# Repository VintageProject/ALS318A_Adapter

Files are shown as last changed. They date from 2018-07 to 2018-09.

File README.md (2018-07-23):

# ALS318A_Adapter
ALS318A to 2x 2364AS adapter for KIM Uno

This board allows to use a Russian ALS318A display to be used with the KIM Uno. It connects the 17-pin connector to a dual 2364AS footprint matching the KIM Uno board.
As the ALS318A is a common cathode type display, the KIM Uno software needs to be adjusted for use with CC displays, too.

Footprint position has been checked against the original KIM Uno board. 
Take care of pin clearances. Solder pins flush to board and use insulating layers if necessary.

Revision 00: Board outline matched to top of KIM Uno board. Might be bulky and interfere with power switch and other connectors.

Revision 01: Short board to match the size of the ALS318A board. Shouldn't interfere with other connectors.

Disclaimer: This is an untested training design. I won't be liable for any damage to your computer and/or electronics if you decide to use it. Use at your own risk.

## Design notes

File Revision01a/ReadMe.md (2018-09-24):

ALS318A to 2x 2364AS adapter for KIM Uno

This board allows to use a Russian ALS318A display to be used with the KIM Uno. It connects the 17-pin connector to a dual 2364AS footprint matching the KIM Uno board. As the ALS318A is a common cathode type display, the KIM Uno software needs to be adjusted for use with CC displays, too.

Footprint position has been checked against the original KIM Uno board. Board outline has been changed so that the adapter board has roughly the size of the ALS318A module. When soldering take care to leave enough room between the header pins and the Arduino pins.
Pin spacing has been changed to 2.5 mm for the ALS318A, and position was adjusted to centred.

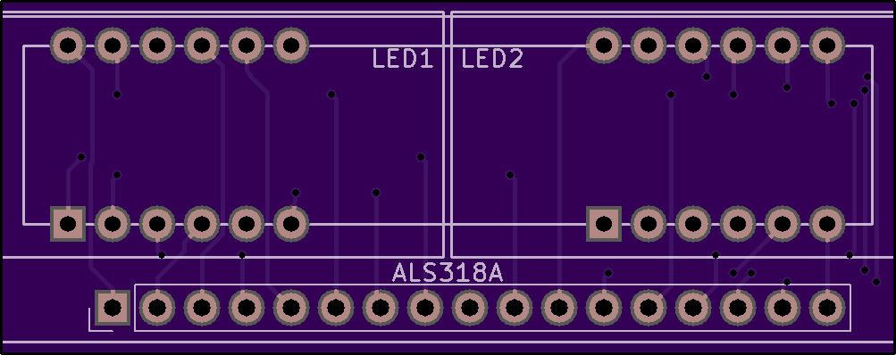
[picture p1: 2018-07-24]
Revision 01/KIMUno ALS318A Display Adapter Rev 01 Gerber Top Render.png

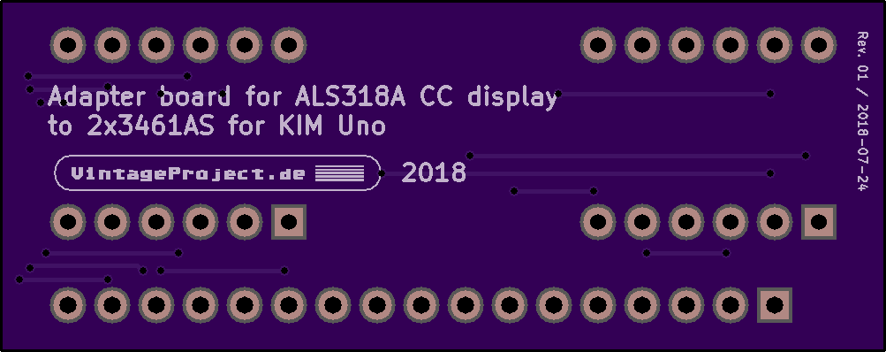
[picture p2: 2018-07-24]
Revision 01/KIMUno ALS318A Display Adapter Rev 01 Gerber Bottom Render.png

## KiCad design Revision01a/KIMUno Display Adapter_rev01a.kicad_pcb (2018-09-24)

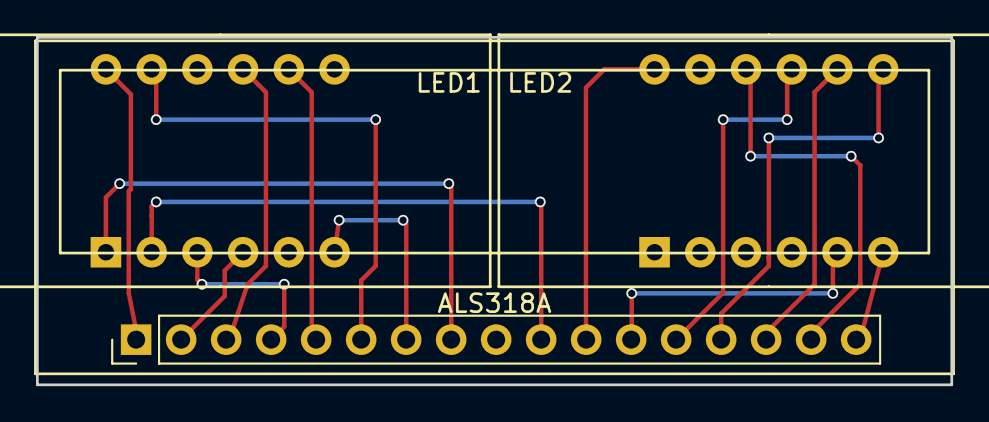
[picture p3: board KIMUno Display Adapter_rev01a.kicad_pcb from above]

Board: 2 copper layers, 50.8 x 19.3 mm, 4 parts (0 on the bottom side), 16 nets.

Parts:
 : LOGO_VintageProject_B.SilkS
J1: ALS318A; ALS318A_BubbleLED_2.5mm
LED1, LED2: CC56-12; 3461AS-BS_4x7SEG-DIGIT_9mm

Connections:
/CC1: J1.1, LED1.12
/CC2: J1.3, LED1.9
/CC3: J1.5, LED1.8
/CC4: J1.7, LED1.6
/CC6: J1.11, LED2.12
/CC7: J1.13, LED2.9
/CC8: J1.15, LED2.8
/CC9: J1.17, LED2.6
/Seg_1a: J1.6, LED1.11
/Seg_1c: J1.2, LED1.4
/Seg_1d: J1.10, LED1.2
/Seg_1e: J1.8, LED1.1
/Seg_1h: J1.4, LED1.3
/Seg_2b: J1.14, LED2.7
/Seg_2f: J1.16, LED2.10
/Seg_2g: J1.12, LED2.5

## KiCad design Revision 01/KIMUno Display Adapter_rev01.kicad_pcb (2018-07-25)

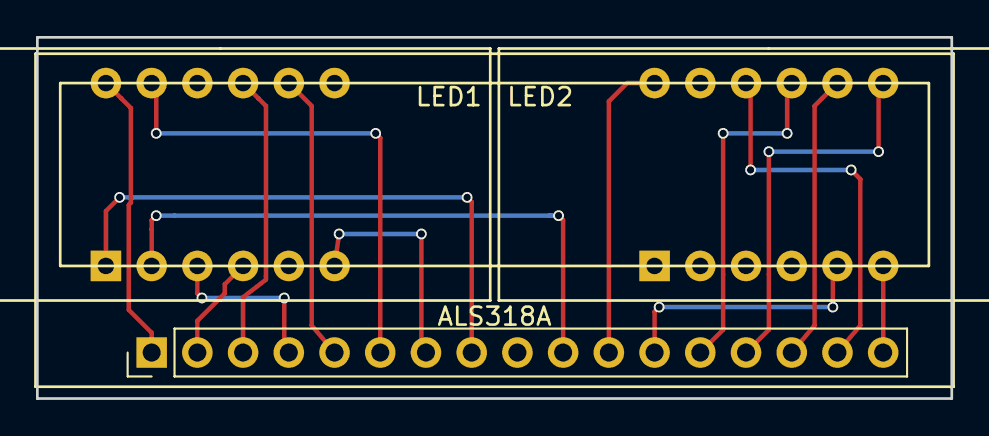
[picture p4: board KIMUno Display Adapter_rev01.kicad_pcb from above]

Board: 2 copper layers, 50.8 x 20.1 mm, 4 parts (0 on the bottom side), 16 nets.

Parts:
 : ALS318A; ALS318A_BubbleLED
 #2: LOGO_VintageProject_B.SilkS
LED1, LED2: CC56-12; 3461AS-BS_4x7SEG-DIGIT_9mm

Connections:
/CC1: .1, LED1.12
/CC2: .3, LED1.9
/CC3: .5, LED1.8
/CC4: .7, LED1.6
/CC6: .11, LED2.12
/CC7: .13, LED2.9
/CC8: .15, LED2.8
/CC9: .17, LED2.6
/Seg_1a: .6, LED1.11
/Seg_1c: .2, LED1.4
/Seg_1d: .10, LED1.2
/Seg_1e: .8, LED1.1
/Seg_1h: .4, LED1.3
/Seg_2b: .14, LED2.7
/Seg_2f: .16, LED2.10
/Seg_2g: .12, LED2.5

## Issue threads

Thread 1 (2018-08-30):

Rev 01: Wrong footprint for ALS318 header

VintageProject, 2018-08-30:
Currently, the header pins I used for the ALS318 connector have the wrong footprint, and placement is off.

I need to replace the header with a version with 2.5 mm pitch.
And the whole row has to be shifted by about 1.5 mm to the left to have the ALS318 board centred on the adapter board.

Closed 2018-09-24.

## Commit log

2018-07-23 Rev. 00 - Initial commit
    [KIMUno Display Adapter.kicad_pcb, KIMUno Display Adapter.sch]
2018-07-23 Rev. 00 - Size adjustment
    [KIMUno Display Adapter.kicad_pcb]
2018-07-23 Revision 01 - Short board
    [KIMUno Display Adapter_rev01.kicad_pcb, KIMUno Display Adapter_rev01.sch]
2018-07-23 Rename KIMUno Display Adapter.sch to Revision 00/KIMUno Display Adapter.sch
    [KIMUno Display Adapter.sch]
2018-07-23 Rename KIMUno Display Adapter.kicad_pcb to Revision 00/KIMUno Display Adapter.kicad_pcb
    [KIMUno Display Adapter.kicad_pcb]
2018-07-23 Reupload Revision 00 - Long board for KIM Uno
2018-07-24 Several changes
    Redid the routing.
    Changed the LED footprint with smaller pads.
    Added logo to underside of the board.
    [KIMUno Display Adapter_rev01.kicad_pcb]
2018-07-25 Rerouted tracks - Short Board for ALS318A
    [KIMUno Display Adapter_rev01.kicad_pcb]
2018-09-24 New layout. Pin spacing corrected and display centred.
    [KIMUno Display Adapter_rev01a.kicad_pcb, KIMUno Display Adapter_rev01a.sch]
2018-09-24 ALS318A Footprint
    For you to play with. :-)
2018-09-24 Error with label visibility corrected.
    [KIMUno Display Adapter_rev01a.kicad_pcb]

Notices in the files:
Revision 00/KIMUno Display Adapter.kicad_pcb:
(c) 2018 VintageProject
